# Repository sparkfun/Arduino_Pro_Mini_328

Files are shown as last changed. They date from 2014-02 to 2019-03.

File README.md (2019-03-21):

Arduino Pro Mini 328
====================

<table class="table table-hover table-striped table-bordered">
  <tr align="center">
   <td><a href="https://www.sparkfun.com/products/11113">Arduino Pro Mini 328 - 5V/16MHz</a></td>
   <td><a href="https://www.sparkfun.com/products/11114">Arduino Pro Mini 328 - 3.3V/8MHz</a></td>
  </tr>
  <tr align="center">
    <td><i>Arduino Pro Mini 328 - 5V/16MHz [<a href="https://www.sparkfun.com/products/11113">DEV-11113</a>]</i></td>
    <td><i>Arduino Pro Mini 328 - 3.3V/8MHz [<a href="https://www.sparkfun.com/products/11114">DEV-11114</a>]</i></td>
  </tr>
</table>

SparkFun's Arduino Pro Mini 328 is a bare bones super small Arduino compatible development board. This hardware is used for both the 3.3V/8MHz and the 5V/16MHz versions. 

Both of these products use the same PCB, but are populated with unique voltage regulators and resonators.

Repository Contents
-------------------
* **/Documentation** - SVG and PDF datasheets for the Pro Mini
* **/Hardware** - Eagle design files (Schematic and Board)
* **/Production** - Test bed files and production panel files

Documentation
--------------
* **[Hookup Guide](https://learn.sparkfun.com/tutorials/using-the-arduino-pro-mini-33v)** - Basic hookup guide for the Arduino Pro Mini 3.3V/8MHz. It can be used as a guide with the 5V. The only difference when following the tutorial is selecting the board definition in the Arduino IDE and the voltage levels.

Product Versions
----------------
* [DEV-11113](https://www.sparkfun.com/products/11113)- 5V/16MHz Pro Mini
* [DEV-15254](https://www.sparkfun.com/products/15254)- 5V/16MHz Pro Mini Starter Kit
* [DEV-11114](https://www.sparkfun.com/products/11114)- 3.3V/8MHz Pro Mini
* [DEV-15257](https://www.sparkfun.com/products/15257)- 3.3V/8MHz Pro Mini Starter Kit 

License Information
-------------------
The hardware is released under [Creative Commons Share-alike 3.0](http://creativecommons.org/licenses/by-sa/3.0/).  

Hardware authors: Original Arduino Mini design by Team Arduino

Pro Mini design by Nathan Seidle @ SparkFun Electonics

Revision work by Pete Lewis @ SparkFun Electonics  

Distributed as-is; no warranty is given.

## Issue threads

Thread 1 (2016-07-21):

Design review for v15

lewispg228, 2016-07-21:
1) Is there a SparkFun Logo? [NO]
comment: Missing logo in sch

2) Is there an OSHW logo? [NO]
comment: missing oshw logo in sch

3) If net labels are used, are they the correct 'FLAG' type? [NO]
comment: A4 and A5 nets off the micro pins could use some flag labels

4) Are dashed grey lines ('info' eagle layer 97) used to clearly separate different areas? [NO]
comment: could be better

5) Do all GND connections use the GND symbol (oriented downward)? [NO]
comment: nets off of JP1, JP7 and JP6

6) Do all VCC connections use the VCC symbol (oriented upward)? [NO]
comment: nets off of JP1 and JP6

7) Is the VCC range clearly labeled? [NO]
comment: Yes, but RAW input range would be useful too

8) Have you verified that the BOM in Sparkle is accurate (also checking for PROD_ID, NAME, VALUE, PREFIX)? [NO]
comment: no PROD_IDs on anything.  value on Q1 should loose the "20MHz", and U1 could use a "ATMEGA328P" (note the "P"), LED1 should be a "D"

9) Do any parts have unnecessary values (Eagle has autoset the package as the value)? [YES]
comment: JP6, JP7

10) Is there a note for a board thickness other than 0.63 inch?  [YES]
comment: I like the large text, but putting in "0.8mm thickness" is what most people are used to, I think both the large text and the number would be great.

11) Is there a URL for any kits or unique boards? [YES]
comment: asked at bug, but it might be a good idea to put the landing page for this product on the bottom silk...

marshalltaylorSFE, 2016-08-02:
These changes were not requested, trying again

Closed 2016-08-02.

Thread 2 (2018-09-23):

ProMini16MHzv1.pdf contains an error

plainpylut, 2018-09-23:
I believe Pin 10, "PORT" identifier "PCB2" to be incorrect.  It should be "PB2".

bboyho, 2019-03-28:
Hi,

I just checked the [Atmega328P datasheet on page 16](https://cdn.sparkfun.com/assets/1/1/9/c/b/Atmel-42735-8-bit-AVR-Microcontroller-ATmega328-328P_Datasheet.pdf). You are correct. =) Nice catch. I'll see what I can do as this is also linked in a different [repository](https://github.com/sparkfun/Graphical_Datasheets/tree/master/Datasheets), the other Pro Mini, and on the product pages.

bboyho, 2019-03-29:
Fixed in this commit => [https://github.com/sparkfun/Arduino_Pro_Mini_328/commit/bcf8de441f8ebe9e21377c4a0d12794670dc2551](https://github.com/sparkfun/Arduino_Pro_Mini_328/commit/bcf8de441f8ebe9e21377c4a0d12794670dc2551)

I also updated the ones in the graphical datasheet here => [https://github.com/sparkfun/Graphical_Datasheets/commit/49f70e6a3971d1523a002636563cfd3526d1e41b](https://github.com/sparkfun/Graphical_Datasheets/commit/49f70e6a3971d1523a002636563cfd3526d1e41b) . I am looking into the product pages and tutorials. =)

bboyho, 2019-04-01:
Product pages are updated with the correct links. Images in tutorials are updated as well. =)

Closed 2019-04-01.

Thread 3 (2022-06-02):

Arduino Pro Mini fuse and lock bytes don't match expected values from Atmel datasheet

bobcruz, 2022-06-02:
After much research, and careful experimentation, I still cannot reconcile the values displayed by AVRdude for the fuse and lock bytes of my Sparkfun Pro Mini against the Atmel datasheet for the ATmega328P microprocessor. I read the values of the fuse and lock bytes using the following command:

`...\avrdude.exe" -C"C:\Users\Bob2\Documents\Ardiuno_IDE-1.8.19_Portable\hardware\tools\avr\etc\avrdude.conf"
-patmega328p -carduino -PCOM3 -b57600  -u -Ulfuse:r:lfuse.hex:i -Uhfuse:r:hfuse.hex:i -Uefuse:r:efuse.hex:i
-Ulock:r:lock.hex:i -v -D`

The resulting output for every one of the fuse bytes and the lock byte as well are all zero (0x00). Yet the Atmel documentation indicates that there should be several non-zero bits within these bytes.
So my question is this: am I doing something wrong when reading these bytes, or is there a reason why they are all actually zero?

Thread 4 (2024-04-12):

Pro Mini 5 start up delay

snussbaum1, 2024-04-12:
I recently designed a system using the Pro Mini 3 and the Pro Mini 5 modules. The mini3 interfaces with the Sparkfun FS-3000 air flow sensor. I've had no issues with this pair.  I've attached a block diagram for reference. Also part of this design is a Pro mini 5 module. This module reads the speed data from the Pro mini 3 and holds it until the I2C master requests it from the Mini 5. The master device is a Spektrum AR637T radio receiver used in electric RC planes. The AR637T receiver sends the speed data to the ground transmitter through the telemetry channel. Everything worked but there was one concern I had. When I programmed the Mini 5 with the Arduino IDE. under the tools menu, I expected I'd have to select the Arduino Pro Mini option with the 5V/Mege 328P version selected. However I could not download to the module after compiling. I tried the selection of Arduino Uno Mini and this worked, i.e. I was able to download and the module worked fine in the system.
I accepted this since everything was working, but it was a concern because it wasn't what I expected.
  However, I ordered 3 more Mini 5s to build up more systems and these new units would NOT allow downloads unless the Arduino Pro Mini was selected along with th5 5v Mega 328P option. Everything compiled and downloaded fine. This is what I expected. But, none of the the modules would not link up with the master over the I2C bus. I dug a little deeper and observed that it takes over 400ms for the Mini 5 code to start executing after power up reset which makes it too late to respond to the initial polling by the bus master. The radio master initial poll for I2C devices comes after 250 ms from power up and if a slave doesn't respond to this first poll, it is not polled again. I tested this by making sure the Mini5 had power before the radio did and it linked up just fine. But in the final design the Radio master, and my Mini 3 and Mini5 all power up together.  I used the Sparkfun FTD module connected to a USB port to download. One for the Mini 3 and another one for the Mini5.
I then saw a post about this and someone suggested to use the ISP method for programming which I set up. Everything downloaded and there was only about a 50 ms delay and the Mini 5 linked up and worked fine.
So my questions are:
   1. Why did the first 2 Mini5 modules not have the 400ms delay out of the box. And I used the USB cable for programming.
   2. Why did the first 2 Mini 5 modules need the Arduino Uno Mini as the board selection and not the Arduino Pro Mini option.
   3. Why did the subsequent 3 Mini 5 modules have a significant start up delay out of the box.
   4.  What is different between these two orders of Mini 5s?

Thank you for helping me with these questions.
Steve
[True Air Speed Sensor for Stall Warning Block Diagram.pdf](https://github.com/sparkfun/Arduino_Pro_Mini_328/files/14963783/True.Air.Speed.Sensor.for.Stall.Warning.Block.Diagram.pdf)

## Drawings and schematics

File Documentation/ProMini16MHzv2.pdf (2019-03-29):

# Arduino Pro Mini (DEV-11113)

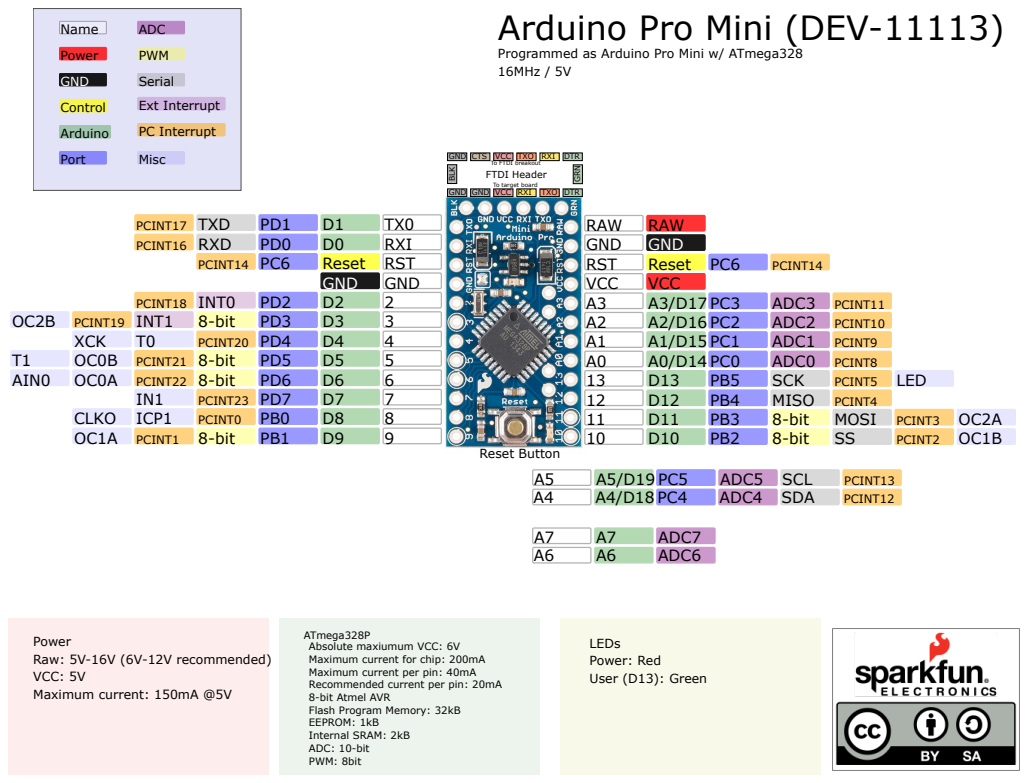
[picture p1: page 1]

Programmed as Arduino Pro Mini w/ ATmega328
16MHz / 5V

ATmega328P
Absolute maxiumum VCC: 6V
Maximum current for chip: 200mA
Maximum current per pin: 40mA
Recommended current per pin: 20mA
8-bit Atmel AVR
Flash Program Memory: 32kB
EEPROM: 1kB
Internal SRAM: 2kB
ADC: 10-bit
PWM: 8bit

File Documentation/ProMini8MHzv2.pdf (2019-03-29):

# Arduino Pro Mini (DEV-11114)

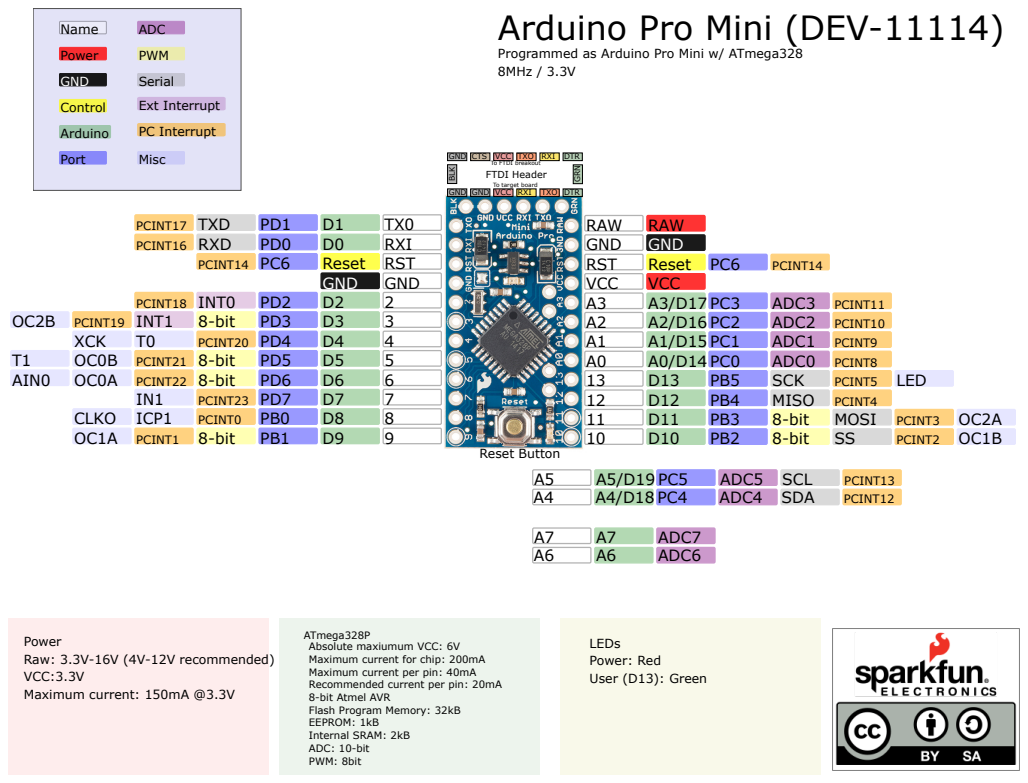
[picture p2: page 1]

Programmed as Arduino Pro Mini w/ ATmega328
8MHz / 3.3V

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

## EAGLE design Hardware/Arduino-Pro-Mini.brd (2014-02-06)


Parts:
C1, C2, C3, C10: 0.1uF; 0603-CAP
C13, C19: 10uF; EIA3216
D3: Green; 0603-LED-ALT1
FRAME1: FRAME-LETTER; CREATIVE_COMMONS
JP1: FTDI Basic; 1X06
JP2, JP3: M02PTH; 1X02
JP5, JP8: FIDUCIALUFIDUCIAL; MICRO-FIDUCIAL
JP6, JP7: M12PTH; 1X12
LED1: Red; 0603-LED-ALT1
Q1: 8/16/20MHz; RESONATOR-SMD-1:1
R1, R3: RESISTOR0603-RES; 0603-RES
R2, R11: 10K; 0603-RES
R6: 330; 0603-RES
S1: Reset; TACTILE-SWITCH-SMD-ALT01
SJ1: SOLDERJUMPERNC; SJ_2S
U1: ATMEGA328; TQFP32-08
U2: MIC5205; SOT23-5
U$1: LOGO-SFESK; SFE-LOGO-FLAME
U$3: OSHW-LOGOS; OSHW-LOGO-S
U$11: LOGO-SFENEW; SFE-NEW-WEBLOGO

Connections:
A0: JP6.8, U1.23 (PC0(ADC0))
A1: JP6.7, U1.24 (PC1(ADC1))
A2: JP6.6, U1.25 (PC2(ADC2))
A3: JP6.5, U1.26 (PC3(ADC3))
A4: JP2.1, R1.1, U1.27 (PC4(ADC4/SDA))
A5: JP2.2, R3.1, U1.28 (PC5(ADC5/SCL))
A6: JP3.1, U1.19 (ADC6)
A7: JP3.2, U1.22 (ADC7)
AREF: C1.2, U1.20 (AREF)
D2: JP7.8, U1.32 (PD2(INT0))
D3: JP7.7, U1.1 (PD3(INT1))
D4: JP7.6, U1.2 (PD4(XCK/T0))
D5: JP7.5, U1.9 (PD5(T1))
D6: JP7.4, U1.10 (PD6(AIN0))
D7: JP7.3, U1.11 (PD7(AIN1))
D8: JP7.2, U1.12 (PB0(ICP))
D9: JP7.1, U1.13 (PB1(OC1A))
D10: JP6.12, U1.14 (PB2(SS/OC1B))
DTR: C2.2, JP1.1 (DTR)
GND: C1.1, C3.1, C10.2, C13.C (-), C19.C (-), D3.C, JP1.5 (CTS), JP1.6 (GND), JP6.2, JP7.9, Q1.2, R11.1, S1.1, S1.2 (1), U1.3 (GND), U1.5 (AGND), U1.21 (GND), U2.2 (GND)
MISO: JP6.10, U1.16 (PB4(MISO))
MOSI: JP6.11, U1.15 (PB3(MOSI/OC2))
unnamed: Q1.3, U1.8 (PB7(XTAL2/TOSC2))
unnamed: Q1.1, U1.7 (PB6(XTAL1/TOSC1))
unnamed: LED1.A, SJ1.1, U2.5 (OUT)
unnamed: LED1.C, R11.2
unnamed: D3.A, R6.2
RAW: C19.A (+), JP6.1, U2.1 (IN), U2.3 (EN)
RESET: C2.1, JP6.3, JP7.10, R2.1, S1.3 (2), S1.4 (2), U1.29 (PC6(/RESET))
RXI: JP1.3 (TXO), JP7.11, U1.30 (PD0(RXD))
SCK: JP6.9, R6.1, U1.17 (PB5(SCK))
TXO: JP1.2 (RXI), JP7.12, U1.31 (PD1(TXD))
VCC: C3.2, C10.1, C13.A (+), JP1.4 (VCC), JP6.4, R1.2, R2.2, R3.2, SJ1.2, U1.4 (VCC), U1.6 (VCC), U1.18 (AVCC)

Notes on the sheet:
Original Arduino Mini Design by Team Arduino
Arduino Pro Mini Design by Spark Fun Electronics
Max Voltage Input: 16VDC
Max Current Output: 150mA
Board is marked with combination of
resonator frequency and regulator voltage.
VCC = 5V or 3.3V Output
Optional Pullups for I2C lines
Off Grid Breakout headers
Power isolation jumper
(for low power aplications)

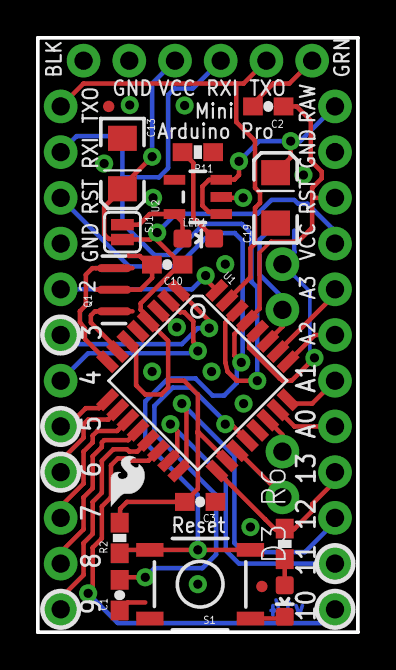
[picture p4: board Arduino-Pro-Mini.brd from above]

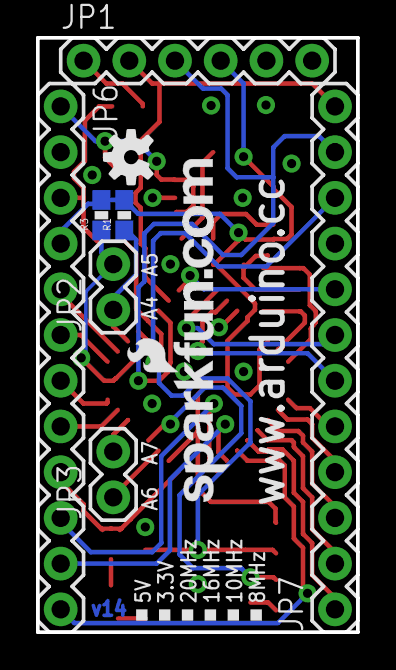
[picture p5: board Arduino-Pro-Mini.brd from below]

Board: 2 copper layers, 17.8 x 33.0 mm, 29 parts (9 on the bottom side), 33 nets.

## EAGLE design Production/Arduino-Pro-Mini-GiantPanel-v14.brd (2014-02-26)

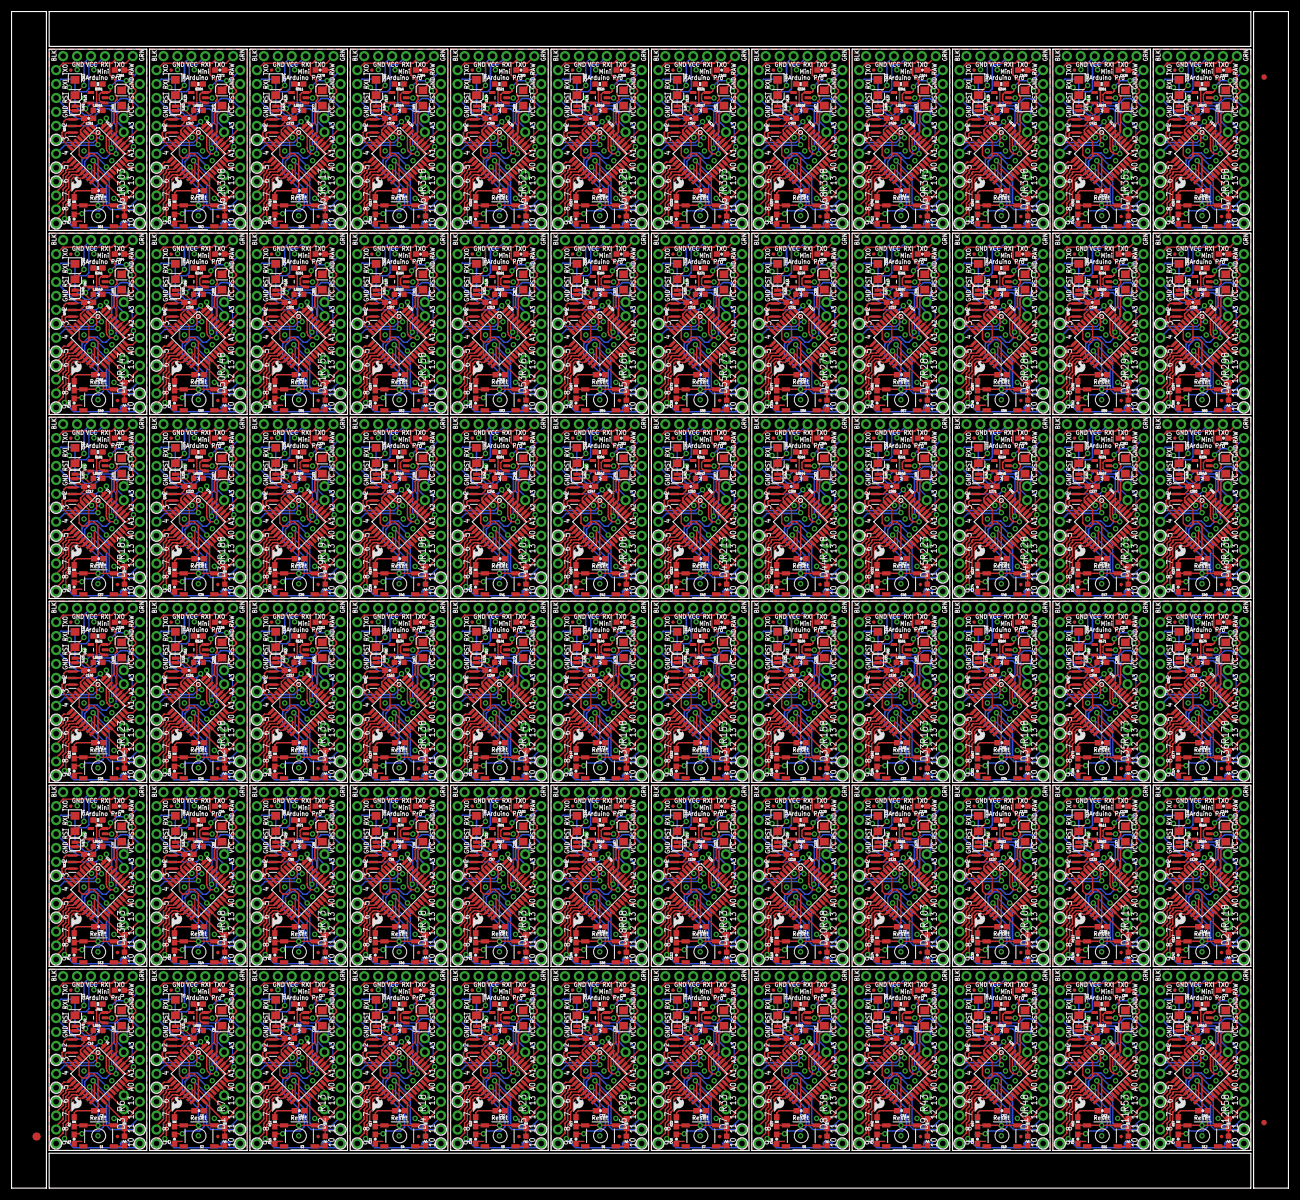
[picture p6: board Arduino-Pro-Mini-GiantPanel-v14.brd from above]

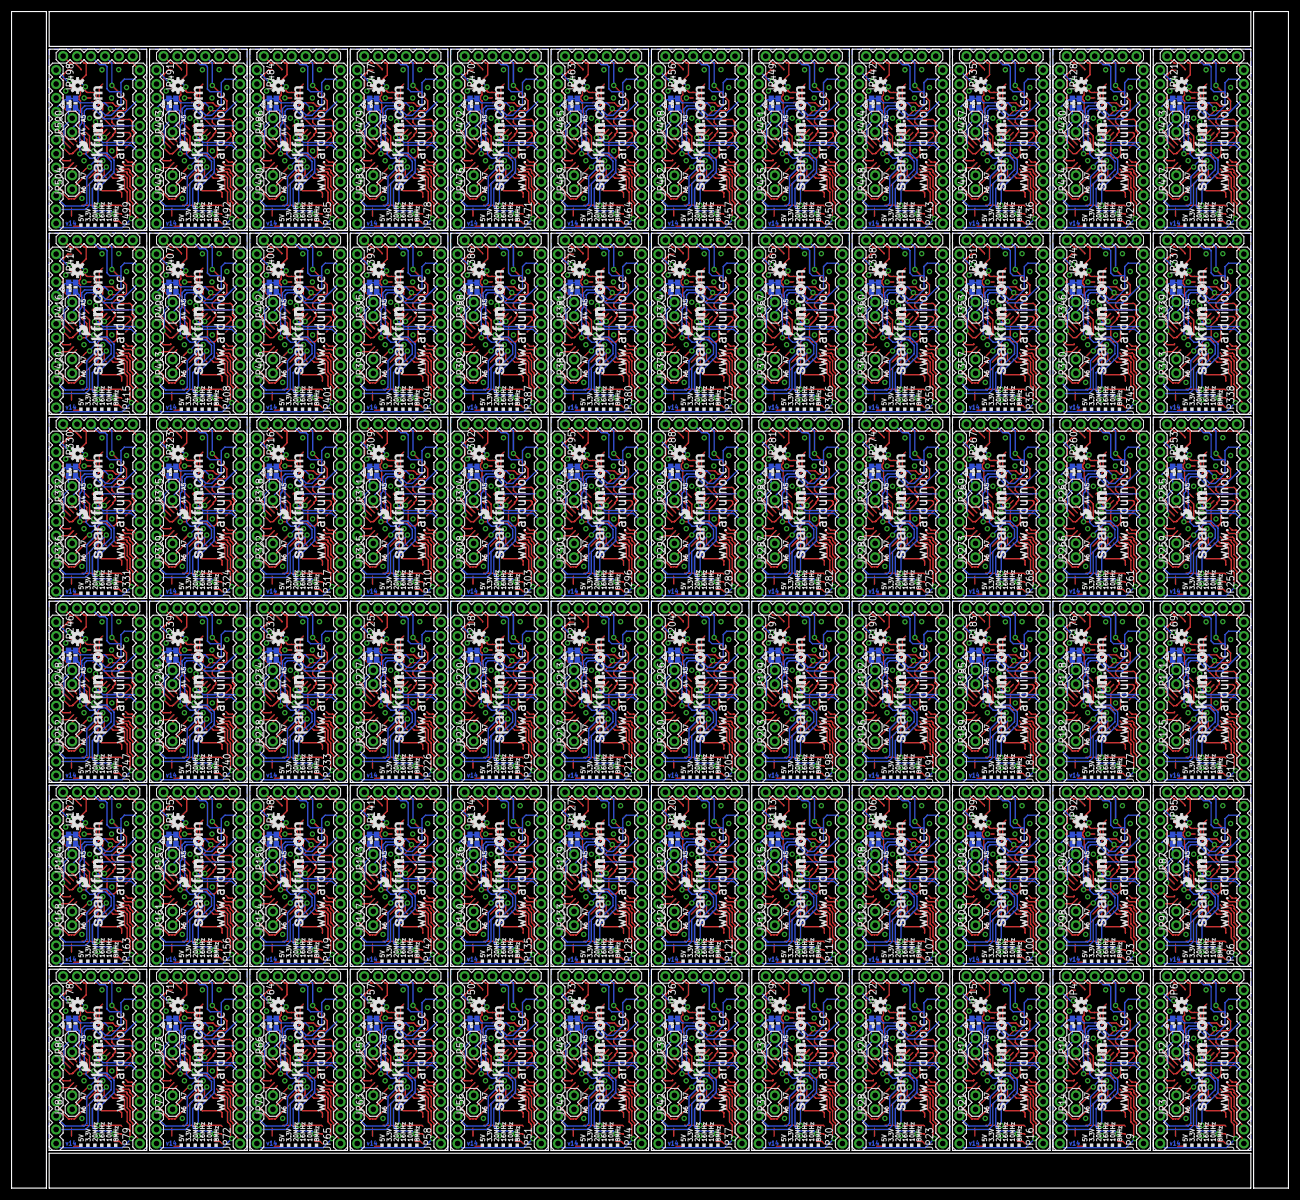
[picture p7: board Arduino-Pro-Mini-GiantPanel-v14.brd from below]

Board: 2 copper layers, 232.7 x 214.4 mm, 2019 parts (648 on the bottom side), 2376 nets.

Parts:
C1, C2, C3, C4, C6, C7, C9, C10, C11, C14, C15, C17, C18, C21, C22, C24, C25, C27, C28, C30, C31, C33, C34, C36, C37, C39, C40, C42, C43, C45, C46, C48, C49, C51, C52, C54, C55, C57, C58, C60, C61, C63, C64, C66, C67, C69, C70, C72, C73, C75, C76, C78, C79, C81, C82, C84, C85, C87, C88, C90, C91, C93, C94, C96, C97, C99, C100, C102, C103, C105, C106, C108, C109, C111, C112, C114, C115, C117, C118, C120, C121, C123, C124, C126, C127, C129, C130, C132, C133, C135, C136, C138, C139, C141, C142, C144, C145, C147, C148, C150, C151, C153, C154, C156, C157, C159, C160, C162, C163, C165, C166, C168, C169, C171, C172, C174, C175, C177, C178, C180, C181, C183, C184, C186, C187, C189, C190, C192, C193, C195, C196, C198, C199, C201, C202, C204, C205, C207, C208, C210, C211, C213, C214, C216, C217, C219, C220, C222, C223, C225, C226, C228, C229, C231, C232, C234, C235, C237, C238, C240, C241, C243, C244, C246, C247, C249, C250, C252, C253, C255, C256, C258, C259, C261, C262, C264, C265, C267, C268, C270, C271, C273, C274, C276, C277, C279, C280, C282, C283, C285, C286, C288, C289, C291, C292, C294, C295, C297, C298, C300, C301, C303, C304, C306, C307, C309, C310, C312, C313, C315, C316, C318, C319, C321, C322, C324, C325, C327, C328, C330, C331, C333, C334, C336, C337, C339, C340, C342, C343, C345, C346, C348, C349, C351, C352, C354, C355, C357, C358, C360, C361, C363, C364, C366, C367, C369, C370, C372, C373, C375, C376, C378, C379, C381, C382, C384, C385, C387, C388, C390, C391, C393, C394, C396, C397, C399, C400, C402, C403, C405, C406, C408, C409, C411, C412, C414, C415, C417, C418, C420, C421, C423, C424, C426, C427, C429, C430, C432: 0.1uF; 0603-CAP
C5, C8, C12, C13, C16, C19, C20, C23, C26, C29, C32, C35, C38, C41, C44, C47, C50, C53, C56, C59, C62, C65, C68, C71, C74, C77, C80, C83, C86, C89, C92, C95, C98, C101, C104, C107, C110, C113, C116, C119, C122, C125, C128, C131, C134, C137, C140, C143, C146, C149, C152, C155, C158, C161, C164, C167, C170, C173, C176, C179, C182, C185, C188, C191, C194, C197, C200, C203, C206, C209, C212, C215, C218, C221, C224, C227, C230, C233, C236, C239, C242, C245, C248, C251, C254, C257, C260, C263, C266, C269, C272, C275, C278, C281, C284, C287, C290, C293, C296, C299, C302, C305, C308, C311, C314, C317, C320, C323, C326, C329, C332, C335, C338, C341, C344, C347, C350, C353, C356, C359, C362, C365, C368, C371, C374, C377, C380, C383, C386, C389, C392, C395, C398, C401, C404, C407, C410, C413, C416, C419, C422, C425, C428, C431: 10uF; EIA3216
D1, D2, D3, D4, D5, D6, D7, D8, D9, D10, D11, D12, D13, D14, D15, D16, D17, D18, D19, D20, D21, D22, D23, D24, D25, D26, D27, D28, D29, D30, D31, D32, D33, D34, D35, D36, D37, D38, D39, D40, D41, D42, D43, D44, D45, D46, D47, D48, D49, D50, D51, D52, D53, D54, D55, D56, D57, D58, D59, D60, D61, D62, D63, D64, D65, D66, D67, D68, D69, D70, D71, D72: Green; 0603-LED-ALT1
E$1: FIDUCIAL-1.5X3
E$4, E$6: FIDUCIAL-1X2
JP1, JP11, JP18, JP25, JP32, JP39, JP46, JP53, JP60, JP67, JP74, JP81, JP88, JP95, JP102, JP109, JP116, JP123, JP130, JP137, JP144, JP151, JP158, JP165, JP172, JP179, JP186, JP193, JP200, JP207, JP214, JP221, JP228, JP235, JP242, JP249, JP256, JP263, JP270, JP277, JP284, JP291, JP298, JP305, JP312, JP319, JP326, JP333, JP340, JP347, JP354, JP361, JP368, JP375, JP382, JP389, JP396, JP403, JP410, JP417, JP424, JP431, JP438, JP445, JP452, JP459, JP466, JP473, JP480, JP487, JP494, JP501: FTDI Basic; 1X06
JP2, JP3, JP10, JP14, JP17, JP21, JP24, JP28, JP31, JP35, JP38, JP42, JP45, JP49, JP52, JP56, JP59, JP63, JP66, JP70, JP73, JP77, JP80, JP84, JP87, JP91, JP94, JP98, JP101, JP105, JP108, JP112, JP115, JP119, JP122, JP126, JP129, JP133, JP136, JP140, JP143, JP147, JP150, JP154, JP157, JP161, JP164, JP168, JP171, JP175, JP178, JP182, JP185, JP189, JP192, JP196, JP199, JP203, JP206, JP210, JP213, JP217, JP220, JP224, JP227, JP231, JP234, JP238, JP241, JP245, JP248, JP252, JP255, JP259, JP262, JP266, JP269, JP273, JP276, JP280, JP283, JP287, JP290, JP294, JP297, JP301, JP304, JP308, JP311, JP315, JP318, JP322, JP325, JP329, JP332, JP336, JP339, JP343, JP346, JP350, JP353, JP357, JP360, JP364, JP367, JP371, JP374, JP378, JP381, JP385, JP388, JP392, JP395, JP399, JP402, JP406, JP409, JP413, JP416, JP420, JP423, JP427, JP430, JP434, JP437, JP441, JP444, JP448, JP451, JP455, JP458, JP462, JP465, JP469, JP472, JP476, JP479, JP483, JP486, JP490, JP493, JP497, JP500, JP504: 1X02
JP4, JP6, JP7, JP9, JP15, JP16, JP22, JP23, JP29, JP30, JP36, JP37, JP43, JP44, JP50, JP51, JP57, JP58, JP64, JP65, JP71, JP72, JP78, JP79, JP85, JP86, JP92, JP93, JP99, JP100, JP106, JP107, JP113, JP114, JP120, JP121, JP127, JP128, JP134, JP135, JP141, JP142, JP148, JP149, JP155, JP156, JP162, JP163, JP169, JP170, JP176, JP177, JP183, JP184, JP190, JP191, JP197, JP198, JP204, JP205, JP211, JP212, JP218, JP219, JP225, JP226, JP232, JP233, JP239, JP240, JP246, JP247, JP253, JP254, JP260, JP261, JP267, JP268, JP274, JP275, JP281, JP282, JP288, JP289, JP295, JP296, JP302, JP303, JP309, JP310, JP316, JP317, JP323, JP324, JP330, JP331, JP337, JP338, JP344, JP345, JP351, JP352, JP358, JP359, JP365, JP366, JP372, JP373, JP379, JP380, JP386, JP387, JP393, JP394, JP400, JP401, JP407, JP408, JP414, JP415, JP421, JP422, JP428, JP429, JP435, JP436, JP442, JP443, JP449, JP450, JP456, JP457, JP463, JP464, JP470, JP471, JP477, JP478, JP484, JP485, JP491, JP492, JP498, JP499: 1X12
JP5, JP8, JP12, JP13, JP19, JP20, JP26, JP27, JP33, JP34, JP40, JP41, JP47, JP48, JP54, JP55, JP61, JP62, JP68, JP69, JP75, JP76, JP82, JP83, JP89, JP90, JP96, JP97, JP103, JP104, JP110, JP111, JP117, JP118, JP124, JP125, JP131, JP132, JP138, JP139, JP145, JP146, JP152, JP153, JP159, JP160, JP166, JP167, JP173, JP174, JP180, JP181, JP187, JP188, JP194, JP195, JP201, JP202, JP208, JP209, JP215, JP216, JP222, JP223, JP229, JP230, JP236, JP237, JP243, JP244, JP250, JP251, JP257, JP258, JP264, JP265, JP271, JP272, JP278, JP279, JP285, JP286, JP292, JP293, JP299, JP300, JP306, JP307, JP313, JP314, JP320, JP321, JP327, JP328, JP334, JP335, JP341, JP342, JP348, JP349, JP355, JP356, JP362, JP363, JP369, JP370, JP376, JP377, JP383, JP384, JP390, JP391, JP397, JP398, JP404, JP405, JP411, JP412, JP418, JP419, JP425, JP426, JP432, JP433, JP439, JP440, JP446, JP447, JP453, JP454, JP460, JP461, JP467, JP468, JP474, JP475, JP481, JP482, JP488, JP489, JP495, JP496, JP502, JP503: FIDUCIALUFIDUCIAL; MICRO-FIDUCIAL
LED1, LED2, LED3, LED4, LED5, LED6, LED7, LED8, LED9, LED10, LED11, LED12, LED13, LED14, LED15, LED16, LED17, LED18, LED19, LED20, LED21, LED22, LED23, LED24, LED25, LED26, LED27, LED28, LED29, LED30, LED31, LED32, LED33, LED34, LED35, LED36, LED37, LED38, LED39, LED40, LED41, LED42, LED43, LED44, LED45, LED46, LED47, LED48, LED49, LED50, LED51, LED52, LED53, LED54, LED55, LED56, LED57, LED58, LED59, LED60, LED61, LED62, LED63, LED64, LED65, LED66, LED67, LED68, LED69, LED70, LED71, LED72: Red; 0603-LED-ALT1
Q1, Q2, Q3, Q4, Q5, Q6, Q7, Q8, Q9, Q10, Q11, Q12, Q13, Q14, Q15, Q16, Q17, Q18, Q19, Q20, Q21, Q22, Q23, Q24, Q25, Q26, Q27, Q28, Q29, Q30, Q31, Q32, Q33, Q34, Q35, Q36, Q37, Q38, Q39, Q40, Q41, Q42, Q43, Q44, Q45, Q46, Q47, Q48, Q49, Q50, Q51, Q52, Q53, Q54, Q55, Q56, Q57, Q58, Q59, Q60, Q61, Q62, Q63, Q64, Q65, Q66, Q67, Q68, Q69, Q70, Q71, Q72: 8/16/20MHz; RESONATOR-SMD-1:1
R1, R3, R8, R9, R14, R15, R19, R20, R24, R25, R29, R30, R34, R35, R39, R40, R44, R45, R49, R50, R54, R55, R59, R60, R64, R65, R69, R70, R74, R75, R79, R80, R84, R85, R89, R90, R94, R95, R99, R100, R104, R105, R109, R110, R114, R115, R119, R120, R124, R125, R129, R130, R134, R135, R139, R140, R144, R145, R149, R150, R154, R155, R159, R160, R164, R165, R169, R170, R174, R175, R179, R180, R184, R185, R189, R190, R194, R195, R199, R200, R204, R205, R209, R210, R214, R215, R219, R220, R224, R225, R229, R230, R234, R235, R239, R240, R244, R245, R249, R250, R254, R255, R259, R260, R264, R265, R269, R270, R274, R275, R279, R280, R284, R285, R289, R290, R294, R295, R299, R300, R304, R305, R309, R310, R314, R315, R319, R320, R324, R325, R329, R330, R334, R335, R339, R340, R344, R345, R349, R350, R354, R355, R359, R360: 0603-RES
R2, R4, R5, R10, R11, R12, R16, R17, R21, R22, R26, R27, R31, R32, R36, R37, R41, R42, R46, R47, R51, R52, R56, R57, R61, R62, R66, R67, R71, R72, R76, R77, R81, R82, R86, R87, R91, R92, R96, R97, R101, R102, R106, R107, R111, R112, R116, R117, R121, R122, R126, R127, R131, R132, R136, R137, R141, R142, R146, R147, R151, R152, R156, R157, R161, R162, R166, R167, R171, R172, R176, R177, R181, R182, R186, R187, R191, R192, R196, R197, R201, R202, R206, R207, R211, R212, R216, R217, R221, R222, R226, R227, R231, R232, R236, R237, R241, R242, R246, R247, R251, R252, R256, R257, R261, R262, R266, R267, R271, R272, R276, R277, R281, R282, R286, R287, R291, R292, R296, R297, R301, R302, R306, R307, R311, R312, R316, R317, R321, R322, R326, R327, R331, R332, R336, R337, R341, R342, R346, R347, R351, R352, R356, R357: 10K; 0603-RES
R6, R7, R13, R18, R23, R28, R33, R38, R43, R48, R53, R58, R63, R68, R73, R78, R83, R88, R93, R98, R103, R108, R113, R118, R123, R128, R133, R138, R143, R148, R153, R158, R163, R168, R173, R178, R183, R188, R193, R198, R203, R208, R213, R218, R223, R228, R233, R238, R243, R248, R253, R258, R263, R268, R273, R278, R283, R288, R293, R298, R303, R308, R313, R318, R323, R328, R333, R338, R343, R348, R353, R358: 330; 0603-RES
S1, S2, S3, S4, S5, S6, S7, S8, S9, S10, S11, S12, S13, S14, S15, S16, S17, S18, S19, S20, S21, S22, S23, S24, S25, S26, S27, S28, S29, S30, S31, S32, S33, S34, S35, S36, S37, S38, S39, S40, S41, S42, S43, S44, S45, S46, S47, S48, S49, S50, S51, S52, S53, S54, S55, S56, S57, S58, S59, S60, S61, S62, S63, S64, S65, S66, S67, S68, S69, S70, S71, S72: Reset; TACTILE-SWITCH-SMD-ALT01
SJ1, SJ2, SJ3, SJ4, SJ5, SJ6, SJ7, SJ8, SJ9, SJ10, SJ11, SJ12, SJ13, SJ14, SJ15, SJ16, SJ17, SJ18, SJ19, SJ20, SJ21, SJ22, SJ23, SJ24, SJ25, SJ26, SJ27, SJ28, SJ29, SJ30, SJ31, SJ32, SJ33, SJ34, SJ35, SJ36, SJ37, SJ38, SJ39, SJ40, SJ41, SJ42, SJ43, SJ44, SJ45, SJ46, SJ47, SJ48, SJ49, SJ50, SJ51, SJ52, SJ53, SJ54, SJ55, SJ56, SJ57, SJ58, SJ59, SJ60, SJ61, SJ62, SJ63, SJ64, SJ65, SJ66, SJ67, SJ68, SJ69, SJ70, SJ71, SJ72: SJ_2S
U1, U4, U6, U8, U10, U12, U14, U16, U18, U20, U22, U24, U26, U28, U30, U32, U34, U36, U38, U40, U42, U44, U46, U48, U50, U52, U54, U56, U58, U60, U62, U64, U66, U68, U70, U72, U74, U76, U78, U80, U82, U84, U86, U88, U90, U92, U94, U96, U98, U100, U102, U104, U106, U108, U110, U112, U114, U116, U118, U120, U122, U124, U126, U128, U130, U132, U134, U136, U138, U140, U142, U144: ATMEGA328; TQFP32-08
U2, U3, U5, U7, U9, U11, U13, U15, U17, U19, U21, U23, U25, U27, U29, U31, U33, U35, U37, U39, U41, U43, U45, U47, U49, U51, U53, U55, U57, U59, U61, U63, U65, U67, U69, U71, U73, U75, U77, U79, U81, U83, U85, U87, U89, U91, U93, U95, U97, U99, U101, U103, U105, U107, U109, U111, U113, U115, U117, U119, U121, U123, U125, U127, U129, U131, U133, U135, U137, U139, U141, U143: MIC5205; SOT23-5
U$1, U$4, U$7, U$10, U$14, U$17, U$20, U$23, U$26, U$29, U$32, U$35, U$38, U$41, U$44, U$47, U$50, U$53, U$56, U$59, U$62, U$65, U$68, U$71, U$74, U$77, U$80, U$83, U$86, U$89, U$92, U$95, U$98, U$101, U$104, U$107, U$110, U$113, U$116, U$119, U$122, U$125, U$128, U$131, U$134, U$137, U$140, U$143, U$146, U$149, U$152, U$155, U$158, U$161, U$164, U$167, U$170, U$173, U$176, U$179, U$182, U$185, U$188, U$191, U$194, U$197, U$200, U$203, U$206, U$209, U$212, U$215: LOGO-SFESK; SFE-LOGO-FLAME
U$2, U$6, U$9, U$11, U$13, U$16, U$19, U$22, U$25, U$28, U$31, U$34, U$37, U$40, U$43, U$46, U$49, U$52, U$55, U$58, U$61, U$64, U$67, U$70, U$73, U$76, U$79, U$82, U$85, U$88, U$91, U$94, U$97, U$100, U$103, U$106, U$109, U$112, U$115, U$118, U$121, U$124, U$127, U$130, U$133, U$136, U$139, U$142, U$145, U$148, U$151, U$154, U$157, U$160, U$163, U$166, U$169, U$172, U$175, U$178, U$181, U$184, U$187, U$190, U$193, U$196, U$199, U$202, U$205, U$208, U$211, U$214: LOGO-SFENEW; SFE-NEW-WEBLOGO
U$3, U$5, U$8, U$12, U$15, U$18, U$21, U$24, U$27, U$30, U$33, U$36, U$39, U$42, U$45, U$48, U$51, U$54, U$57, U$60, U$63, U$66, U$69, U$72, U$75, U$78, U$81, U$84, U$87, U$90, U$93, U$96, U$99, U$102, U$105, U$108, U$111, U$114, U$117, U$120, U$123, U$126, U$129, U$132, U$135, U$138, U$141, U$144, U$147, U$150, U$153, U$156, U$159, U$162, U$165, U$168, U$171, U$174, U$177, U$180, U$183, U$186, U$189, U$192, U$195, U$198, U$201, U$204, U$207, U$210, U$213, U$216: OSHW-LOGOS; OSHW-LOGO-S

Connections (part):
A0: JP6.8, U1.23
A1: JP6.7, U1.24
A2: JP6.6, U1.25
A3: JP6.5, U1.26
A4: JP2.1, R1.1, U1.27
A5: JP2.2, R3.1, U1.28
A6: JP3.1, U1.19
A7: JP3.2, U1.22
A8: JP10.2, R9.1, U4.28
A9: JP10.1, R8.1, U4.27
A10: JP4.5, U4.26
A11: JP4.6, U4.25
A12: JP4.7, U4.24
A13: JP4.8, U4.23
A14: JP14.1, U4.19
A15: JP14.2, U4.22
A16: JP17.2, R15.1, U6.28
A17: JP17.1, R14.1, U6.27
A18: JP15.5, U6.26
A19: JP15.6, U6.25
A20: JP15.7, U6.24
A21: JP15.8, U6.23
A22: JP21.1, U6.19
A23: JP21.2, U6.22
A24: JP24.2, R20.1, U8.28
A25: JP24.1, R19.1, U8.27
A26: JP22.5, U8.26
A27: JP22.6, U8.25
A28: JP22.7, U8.24
A29: JP22.8, U8.23
A30: JP28.1, U8.19
A31: JP28.2, U8.22
A32: JP31.2, R25.1, U10.28
A33: JP31.1, R24.1, U10.27
A34: JP29.5, U10.26
A35: JP29.6, U10.25
A36: JP29.7, U10.24
A37: JP29.8, U10.23
A38: JP35.1, U10.19
A39: JP35.2, U10.22
A40: JP38.2, R30.1, U12.28
A41: JP38.1, R29.1, U12.27
A42: JP36.5, U12.26
A43: JP36.6, U12.25
A44: JP36.7, U12.24
A45: JP36.8, U12.23
A46: JP42.1, U12.19
A47: JP42.2, U12.22
A48: JP45.2, R35.1, U14.28
A49: JP45.1, R34.1, U14.27
A50: JP43.5, U14.26
A51: JP43.6, U14.25
A52: JP43.7, U14.24
A53: JP43.8, U14.23
A54: JP49.1, U14.19
A55: JP49.2, U14.22
A56: JP52.2, R40.1, U16.28
A57: JP52.1, R39.1, U16.27
A58: JP50.5, U16.26
A59: JP50.6, U16.25
A60: JP50.7, U16.24
A61: JP50.8, U16.23
A62: JP56.1, U16.19
A63: JP56.2, U16.22
A64: JP59.2, R45.1, U18.28
A65: JP59.1, R44.1, U18.27
A66: JP57.5, U18.26
A67: JP57.6, U18.25
A68: JP57.7, U18.24
A69: JP57.8, U18.23
A70: JP63.1, U18.19
A71: JP63.2, U18.22
A72: JP66.2, R50.1, U20.28
A73: JP66.1, R49.1, U20.27
A74: JP64.5, U20.26
A75: JP64.6, U20.25
A76: JP64.7, U20.24
A77: JP64.8, U20.23
A78: JP70.1, U20.19
A79: JP70.2, U20.22
A80: JP73.2, R55.1, U22.28
A81: JP73.1, R54.1, U22.27
A82: JP71.5, U22.26
A83: JP71.6, U22.25
A84: JP71.7, U22.24
A85: JP71.8, U22.23
A86: JP77.1, U22.19
A87: JP77.2, U22.22
A88: JP80.2, R60.1, U24.28
A89: JP80.1, R59.1, U24.27
A90: JP78.5, U24.26
A91: JP78.6, U24.25
A92: JP78.7, U24.24
A93: JP78.8, U24.23
A94: JP84.1, U24.19
A95: JP84.2, U24.22
A96: JP87.2, R65.1, U26.28
A97: JP87.1, R64.1, U26.27
A98: JP85.5, U26.26
A99: JP85.6, U26.25
A100: JP85.7, U26.24
A101: JP85.8, U26.23
A102: JP91.1, U26.19
A103: JP91.2, U26.22
A104: JP94.2, R70.1, U28.28
A105: JP94.1, R69.1, U28.27
A106: JP92.5, U28.26
A107: JP92.6, U28.25
A108: JP92.7, U28.24
A109: JP92.8, U28.23
A110: JP98.1, U28.19
A111: JP98.2, U28.22
A112: JP101.2, R75.1, U30.28
A113: JP101.1, R74.1, U30.27
A114: JP99.5, U30.26
A115: JP99.6, U30.25
A116: JP99.7, U30.24
A117: JP99.8, U30.23
A118: JP105.1, U30.19
A119: JP105.2, U30.22
A120: JP108.2, R80.1, U32.28
A121: JP108.1, R79.1, U32.27
A122: JP106.5, U32.26
A123: JP106.6, U32.25
A124: JP106.7, U32.24
A125: JP106.8, U32.23
A126: JP112.1, U32.19
A127: JP112.2, U32.22
A128: JP115.2, R85.1, U34.28
A129: JP115.1, R84.1, U34.27
A130: JP113.5, U34.26
A131: JP113.6, U34.25
A132: JP113.7, U34.24
A133: JP113.8, U34.23
A134: JP119.1, U34.19
A135: JP119.2, U34.22
A136: JP122.2, R90.1, U36.28
A137: JP122.1, R89.1, U36.27
A138: JP120.5, U36.26
A139: JP120.6, U36.25
A140: JP120.7, U36.24
A141: JP120.8, U36.23
A142: JP126.1, U36.19
A143: JP126.2, U36.22
A144: JP129.2, R95.1, U38.28
A145: JP129.1, R94.1, U38.27
A146: JP127.5, U38.26
A147: JP127.6, U38.25
A148: JP127.7, U38.24
A149: JP127.8, U38.23
A150: JP133.1, U38.19
A151: JP133.2, U38.22
A152: JP136.2, R100.1, U40.28
A153: JP136.1, R99.1, U40.27
A154: JP134.5, U40.26
A155: JP134.6, U40.25
A156: JP134.7, U40.24
A157: JP134.8, U40.23
A158: JP140.1, U40.19
A159: JP140.2, U40.22
A160: JP143.2, R105.1, U42.28
A161: JP143.1, R104.1, U42.27
A162: JP141.5, U42.26
A163: JP141.6, U42.25
A164: JP141.7, U42.24
A165: JP141.8, U42.23
A166: JP147.1, U42.19
A167: JP147.2, U42.22
A168: JP150.2, R110.1, U44.28
A169: JP150.1, R109.1, U44.27
A170: JP148.5, U44.26
A171: JP148.6, U44.25
A172: JP148.7, U44.24
A173: JP148.8, U44.23
A174: JP154.1, U44.19
A175: JP154.2, U44.22
A176: JP157.2, R115.1, U46.28
A177: JP157.1, R114.1, U46.27
A178: JP155.5, U46.26
A179: JP155.6, U46.25
A180: JP155.7, U46.24
A181: JP155.8, U46.23
A182: JP161.1, U46.19
A183: JP161.2, U46.22
A184: JP164.2, R120.1, U48.28
A185: JP164.1, R119.1, U48.27
A186: JP162.5, U48.26
A187: JP162.6, U48.25
A188: JP162.7, U48.24
A189: JP162.8, U48.23
A190: JP168.1, U48.19
A191: JP168.2, U48.22
A192: JP171.2, R125.1, U50.28
A193: JP171.1, R124.1, U50.27
A194: JP169.5, U50.26
A195: JP169.6, U50.25
A196: JP169.7, U50.24
A197: JP169.8, U50.23
A198: JP175.1, U50.19
A199: JP175.2, U50.22
A200: JP178.2, R130.1, U52.28
A201: JP178.1, R129.1, U52.27
A202: JP176.5, U52.26
A203: JP176.6, U52.25
A204: JP176.7, U52.24
A205: JP176.8, U52.23
A206: JP182.1, U52.19
A207: JP182.2, U52.22
A208: JP185.2, R135.1, U54.28
A209: JP185.1, R134.1, U54.27
A210: JP183.5, U54.26
A211: JP183.6, U54.25
A212: JP183.7, U54.24
A213: JP183.8, U54.23
A214: JP189.1, U54.19
A215: JP189.2, U54.22
A216: JP192.2, R140.1, U56.28
A217: JP192.1, R139.1, U56.27
A218: JP190.5, U56.26
A219: JP190.6, U56.25
A220: JP190.7, U56.24
A221: JP190.8, U56.23
A222: JP196.1, U56.19
A223: JP196.2, U56.22
A224: JP199.2, R145.1, U58.28
A225: JP199.1, R144.1, U58.27
A226: JP197.5, U58.26
A227: JP197.6, U58.25
A228: JP197.7, U58.24
A229: JP197.8, U58.23
A230: JP203.1, U58.19
A231: JP203.2, U58.22
A232: JP206.2, R150.1, U60.28
A233: JP206.1, R149.1, U60.27
A234: JP204.5, U60.26
A235: JP204.6, U60.25
A236: JP204.7, U60.24
A237: JP204.8, U60.23
A238: JP210.1, U60.19
A239: JP210.2, U60.22
A240: JP213.2, R155.1, U62.28
A241: JP213.1, R154.1, U62.27
A242: JP211.5, U62.26
A243: JP211.6, U62.25
A244: JP211.7, U62.24
A245: JP211.8, U62.23
A246: JP217.1, U62.19
A247: JP217.2, U62.22
A248: JP220.2, R160.1, U64.28
A249: JP220.1, R159.1, U64.27
A250: JP218.5, U64.26
A251: JP218.6, U64.25
A252: JP218.7, U64.24
A253: JP218.8, U64.23
A254: JP224.1, U64.19
A255: JP224.2, U64.22
A256: JP227.2, R165.1, U66.28
A257: JP227.1, R164.1, U66.27
A258: JP225.5, U66.26
A259: JP225.6, U66.25
A260: JP225.7, U66.24
A261: JP225.8, U66.23
A262: JP231.1, U66.19
A263: JP231.2, U66.22
A264: JP234.2, R170.1, U68.28
A265: JP234.1, R169.1, U68.27
A266: JP232.5, U68.26
A267: JP232.6, U68.25
A268: JP232.7, U68.24
A269: JP232.8, U68.23
A270: JP238.1, U68.19
A271: JP238.2, U68.22
A272: JP241.2, R175.1, U70.28
A273: JP241.1, R174.1, U70.27
A274: JP239.5, U70.26
A275: JP239.6, U70.25
A276: JP239.7, U70.24
A277: JP239.8, U70.23
A278: JP245.1, U70.19
A279: JP245.2, U70.22
A280: JP248.2, R180.1, U72.28
A281: JP248.1, R179.1, U72.27
A282: JP246.5, U72.26
A283: JP246.6, U72.25
A284: JP246.7, U72.24
A285: JP246.8, U72.23
A286: JP252.1, U72.19
A287: JP252.2, U72.22
A288: JP255.2, R185.1, U74.28
A289: JP255.1, R184.1, U74.27
A290: JP253.5, U74.26
A291: JP253.6, U74.25
A292: JP253.7, U74.24
A293: JP253.8, U74.23
A294: JP259.1, U74.19
A295: JP259.2, U74.22
A296: JP262.2, R190.1, U76.28
A297: JP262.1, R189.1, U76.27
A298: JP260.5, U76.26
A299: JP260.6, U76.25
A300: JP260.7, U76.24
A301: JP260.8, U76.23
A302: JP266.1, U76.19
A303: JP266.2, U76.22
A304: JP269.2, R195.1, U78.28
A305: JP269.1, R194.1, U78.27
A306: JP267.5, U78.26
A307: JP267.6, U78.25
A308: JP267.7, U78.24
A309: JP267.8, U78.23
A310: JP273.1, U78.19
A311: JP273.2, U78.22
A312: JP276.2, R200.1, U80.28
A313: JP276.1, R199.1, U80.27
A314: JP274.5, U80.26
A315: JP274.6, U80.25
A316: JP274.7, U80.24
A317: JP274.8, U80.23
A318: JP280.1, U80.19
A319: JP280.2, U80.22
A320: JP283.2, R205.1, U82.28
A321: JP283.1, R204.1, U82.27
A322: JP281.5, U82.26
A323: JP281.6, U82.25
A324: JP281.7, U82.24
A325: JP281.8, U82.23
A326: JP287.1, U82.19
A327: JP287.2, U82.22
A328: JP290.2, R210.1, U84.28
A329: JP290.1, R209.1, U84.27
A330: JP288.5, U84.26
A331: JP288.6, U84.25
A332: JP288.7, U84.24
A333: JP288.8, U84.23
A334: JP294.1, U84.19
A335: JP294.2, U84.22
A336: JP297.2, R215.1, U86.28
A337: JP297.1, R214.1, U86.27
A338: JP295.5, U86.26
A339: JP295.6, U86.25
A340: JP295.7, U86.24
A341: JP295.8, U86.23
A342: JP301.1, U86.19
A343: JP301.2, U86.22
A344: JP304.2, R220.1, U88.28
A345: JP304.1, R219.1, U88.27
A346: JP302.5, U88.26
A347: JP302.6, U88.25
A348: JP302.7, U88.24
A349: JP302.8, U88.23
A350: JP308.1, U88.19
A351: JP308.2, U88.22
A352: JP311.2, R225.1, U90.28
A353: JP311.1, R224.1, U90.27
A354: JP309.5, U90.26
A355: JP309.6, U90.25
A356: JP309.7, U90.24
A357: JP309.8, U90.23
A358: JP315.1, U90.19
A359: JP315.2, U90.22
A360: JP318.2, R230.1, U92.28
A361: JP318.1, R229.1, U92.27
A362: JP316.5, U92.26
A363: JP316.6, U92.25
A364: JP316.7, U92.24
A365: JP316.8, U92.23
A366: JP322.1, U92.19
A367: JP322.2, U92.22
A368: JP325.2, R235.1, U94.28
A369: JP325.1, R234.1, U94.27
A370: JP323.5, U94.26
A371: JP323.6, U94.25
A372: JP323.7, U94.24
A373: JP323.8, U94.23
A374: JP329.1, U94.19
A375: JP329.2, U94.22
A376: JP332.2, R240.1, U96.28
A377: JP332.1, R239.1, U96.27
A378: JP330.5, U96.26
A379: JP330.6, U96.25
A380: JP330.7, U96.24
A381: JP330.8, U96.23
A382: JP336.1, U96.19
A383: JP336.2, U96.22
A384: JP339.2, R245.1, U98.28
A385: JP339.1, R244.1, U98.27
A386: JP337.5, U98.26
A387: JP337.6, U98.25
A388: JP337.7, U98.24
A389: JP337.8, U98.23
A390: JP343.1, U98.19
A391: JP343.2, U98.22
A392: JP346.2, R250.1, U100.28
A393: JP346.1, R249.1, U100.27
A394: JP344.5, U100.26
A395: JP344.6, U100.25
A396: JP344.7, U100.24
A397: JP344.8, U100.23
A398: JP350.1, U100.19
A399: JP350.2, U100.22
A400: JP353.2, R255.1, U102.28
A401: JP353.1, R254.1, U102.27
A402: JP351.5, U102.26
A403: JP351.6, U102.25
A404: JP351.7, U102.24
A405: JP351.8, U102.23
A406: JP357.1, U102.19
A407: JP357.2, U102.22
A408: JP360.2, R260.1, U104.28
A409: JP360.1, R259.1, U104.27
A410: JP358.5, U104.26
A411: JP358.6, U104.25
A412: JP358.7, U104.24
A413: JP358.8, U104.23
A414: JP364.1, U104.19
A415: JP364.2, U104.22
A416: JP367.2, R265.1, U106.28
A417: JP367.1, R264.1, U106.27
A418: JP365.5, U106.26
A419: JP365.6, U106.25
A420: JP365.7, U106.24
A421: JP365.8, U106.23
A422: JP371.1, U106.19
A423: JP371.2, U106.22
A424: JP374.2, R270.1, U108.28
A425: JP374.1, R269.1, U108.27
A426: JP372.5, U108.26
A427: JP372.6, U108.25
A428: JP372.7, U108.24
A429: JP372.8, U108.23
A430: JP378.1, U108.19
A431: JP378.2, U108.22
A432: JP381.2, R275.1, U110.28
A433: JP381.1, R274.1, U110.27
A434: JP379.5, U110.26
A435: JP379.6, U110.25
A436: JP379.7, U110.24
A437: JP379.8, U110.23
A438: JP385.1, U110.19
A439: JP385.2, U110.22
A440: JP388.2, R280.1, U112.28
A441: JP388.1, R279.1, U112.27
A442: JP386.5, U112.26
A443: JP386.6, U112.25
A444: JP386.7, U112.24
A445: JP386.8, U112.23
A446: JP392.1, U112.19
A447: JP392.2, U112.22
A448: JP395.2, R285.1, U114.28
A449: JP395.1, R284.1, U114.27
A450: JP393.5, U114.26
A451: JP393.6, U114.25
A452: JP393.7, U114.24
A453: JP393.8, U114.23
A454: JP399.1, U114.19
A455: JP399.2, U114.22
A456: JP402.2, R290.1, U116.28
A457: JP402.1, R289.1, U116.27
A458: JP400.5, U116.26
A459: JP400.6, U116.25
A460: JP400.7, U116.24
A461: JP400.8, U116.23
A462: JP406.1, U116.19
A463: JP406.2, U116.22
A464: JP409.2, R295.1, U118.28
A465: JP409.1, R294.1, U118.27
A466: JP407.5, U118.26
A467: JP407.6, U118.25
A468: JP407.7, U118.24
A469: JP407.8, U118.23
A470: JP413.1, U118.19
A471: JP413.2, U118.22
A472: JP416.2, R300.1, U120.28
A473: JP416.1, R299.1, U120.27
A474: JP414.5, U120.26
A475: JP414.6, U120.25
A476: JP414.7, U120.24
A477: JP414.8, U120.23
A478: JP420.1, U120.19
A479: JP420.2, U120.22
A480: JP423.2, R305.1, U122.28
A481: JP423.1, R304.1, U122.27
A482: JP421.5, U122.26
A483: JP421.6, U122.25
A484: JP421.7, U122.24
A485: JP421.8, U122.23
A486: JP427.1, U122.19
A487: JP427.2, U122.22
A488: JP430.2, R310.1, U124.28
A489: JP430.1, R309.1, U124.27
A490: JP428.5, U124.26
A491: JP428.6, U124.25
A492: JP428.7, U124.24
A493: JP428.8, U124.23
A494: JP434.1, U124.19
A495: JP434.2, U124.22
A496: JP437.2, R315.1, U126.28
A497: JP437.1, R314.1, U126.27
A498: JP435.5, U126.26
A499: JP435.6, U126.25
A500: JP435.7, U126.24
A501: JP435.8, U126.23
A502: JP441.1, U126.19
A503: JP441.2, U126.22
A504: JP444.2, R320.1, U128.28
A505: JP444.1, R319.1, U128.27
A506: JP442.5, U128.26
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

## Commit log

2014-01-23 initial commit of hardware (v13)
    [Arduino-Pro-Mini.brd, Arduino-Pro-Mini.sch]
2014-01-23 moved al FPs to 0603
    Also fixes all the angle errors in traces coming off of IC.
2014-01-23 updated frame in SCH
    [Arduino-Pro-Mini.sch]
2014-01-24 Added power isolation jumper
    [Arduino-Pro-Mini.brd, Arduino-Pro-Mini.sch]
2014-01-31 footprint updates, schematic work
    -reset button, moved pads out for more toe
    -resonator, 1:1 with fake traces
    -moved all labels to flags in sch
    -moved A6/A7 header to 2X1, rather than singles
    [Arduino-Pro-Mini.brd, Arduino-Pro-Mini.sch]
2014-02-06 deleted eagle backup files
    [Arduino-Pro-Mini.brd]
2014-02-06 v14 ready for protos
    changed led footprint to cloaser to true 0603
    [Arduino-Pro-Mini.brd, Arduino-Pro-Mini.sch]
2014-02-26 Created Giant Panel v14
    [Arduino-Pro-Mini-GiantPanel-v14.brd]
2015-06-22 Updating directory name to prevent OS errors
    [Arduino-Pro-Mini-GiantPanel-v14.brd]
2019-03-29 Correct Port Name on Pin 10
    - Corrected pin name from "PCB2" to "PB2"
    - Rename files based on the correction

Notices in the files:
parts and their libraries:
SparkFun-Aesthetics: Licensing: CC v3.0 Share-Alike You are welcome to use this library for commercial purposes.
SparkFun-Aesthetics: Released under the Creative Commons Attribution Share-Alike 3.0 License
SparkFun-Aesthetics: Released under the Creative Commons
